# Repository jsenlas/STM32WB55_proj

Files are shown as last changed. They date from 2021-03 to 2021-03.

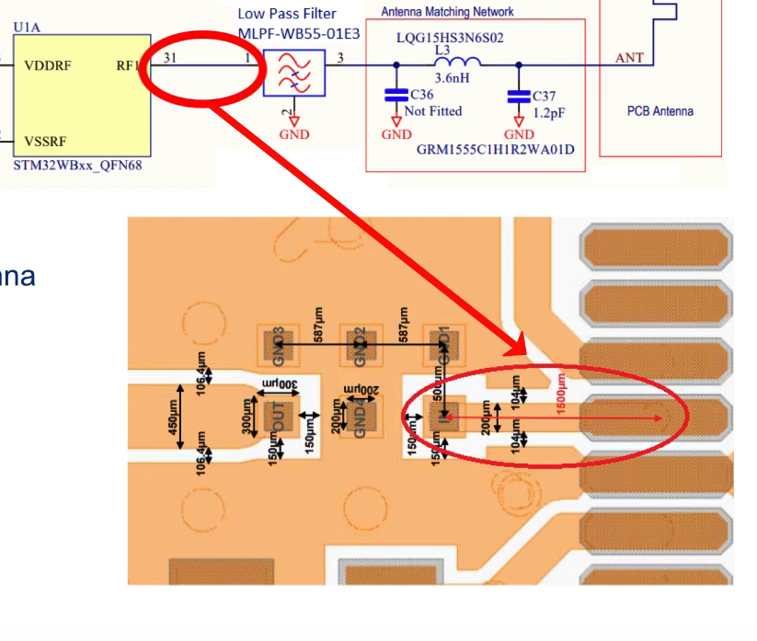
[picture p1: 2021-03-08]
pic/RF.png

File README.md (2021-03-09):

# STM32WB55_proj

# Changelist
v01 
pred touto verziou boli len inicializacne commity
Zacal som minimalizaciu (susciastky blizsie a hustejsie), napriek tomu, ze este nemam spatnu vazbu, no je lepsie ked si prejdem umiestnenie a rozlozenie vsetkych suciastok.
Differential pair pre USB W0.341mm Separator0.2mm to by malo zarucit 90Ohm impedanciu.
Upratovanie Silkscreenu
Pridane 3d Modely .step subory

v02 8.3.2021
- otrasovane
- vyplnene plochy GND
- opravene vsetky chyby, ktore vznikali pri design rules checku
- pridanych par obrazkov, v ktorych je ulozene nastavenie pre niektore operacie, hlavne zony

v03 9.3.2021
- opravene RF trasy - zaoblenie, solder mask, vzdialenost vzhladom na dlzku anteny
- posunute USB dalej, aby som vytvoril priestor a napravil tak dalsie chyby kde sa mi prekryvali suciastky

ToDo:
- [] vyplnit priestor s vias na GND
- [] nepaci sa mi ako je poprepajane I2C (chaos) a USB (+ a - su prilis blizko pri sebe v USBLC6-2SC6)
- [x] doplnit "ohradu" z  GND vias okolo RF tras - nie je miesto

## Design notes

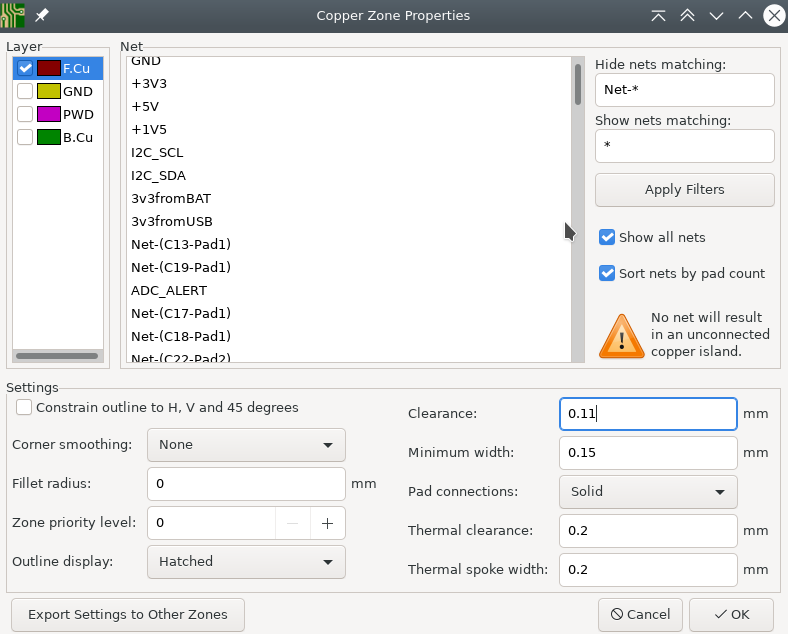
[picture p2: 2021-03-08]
pic/impedance_i2C.png

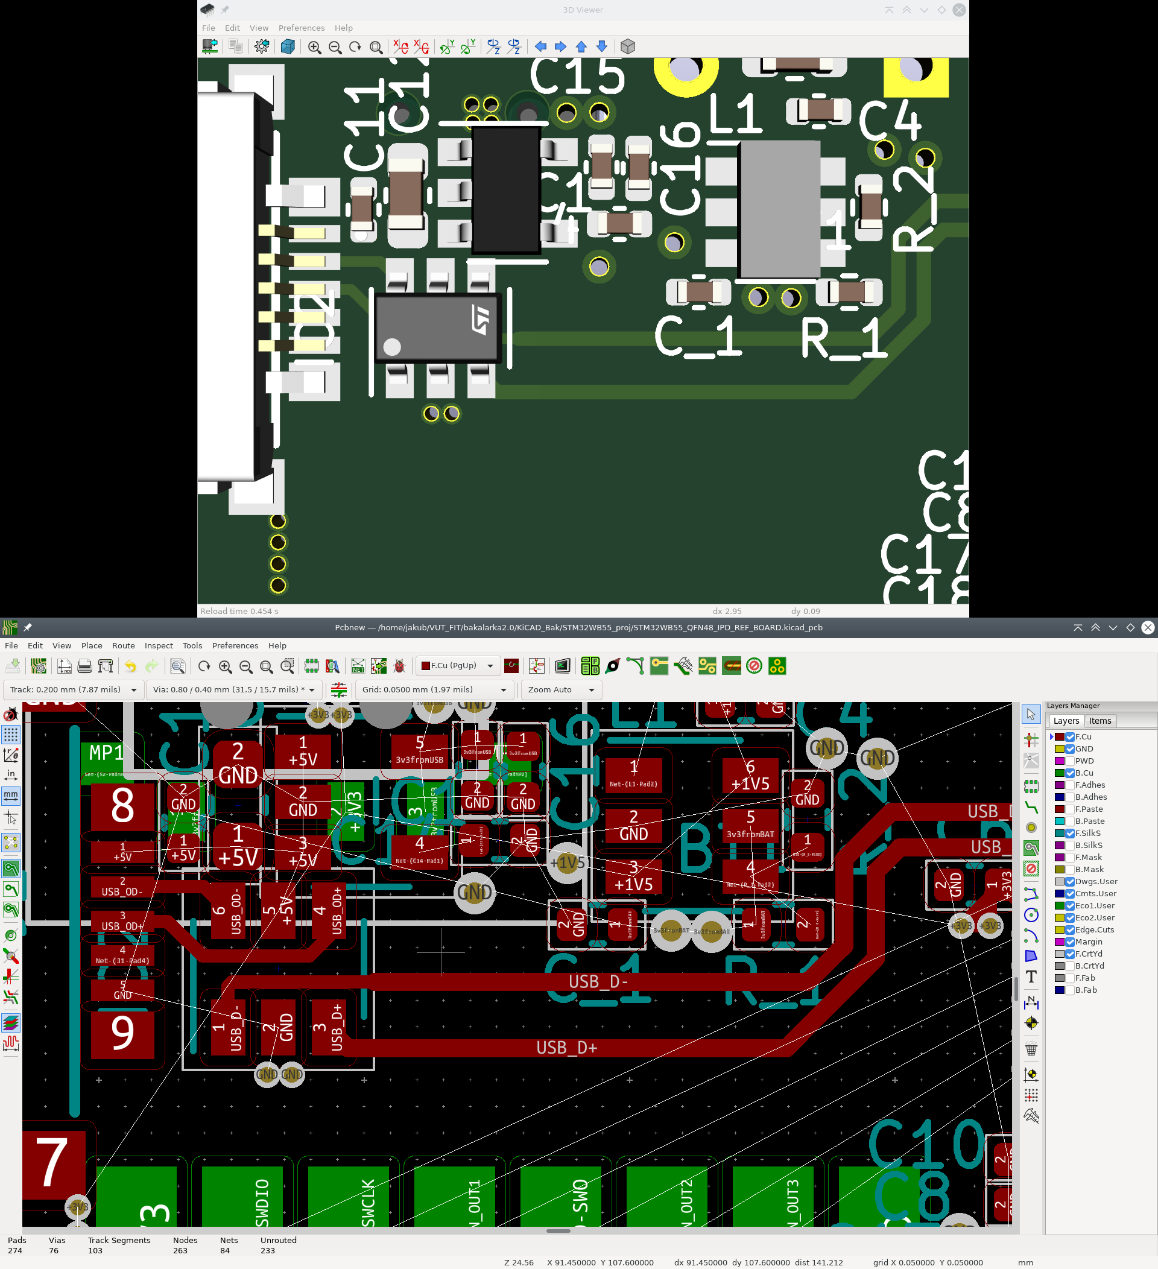
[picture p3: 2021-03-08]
pic/USB_straight.png

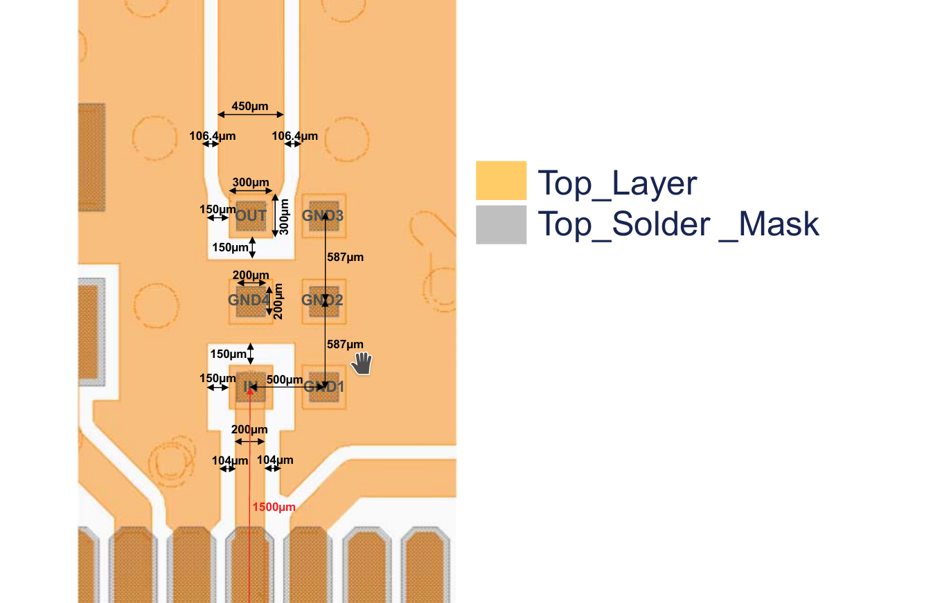
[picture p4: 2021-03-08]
pic/RF_org.png

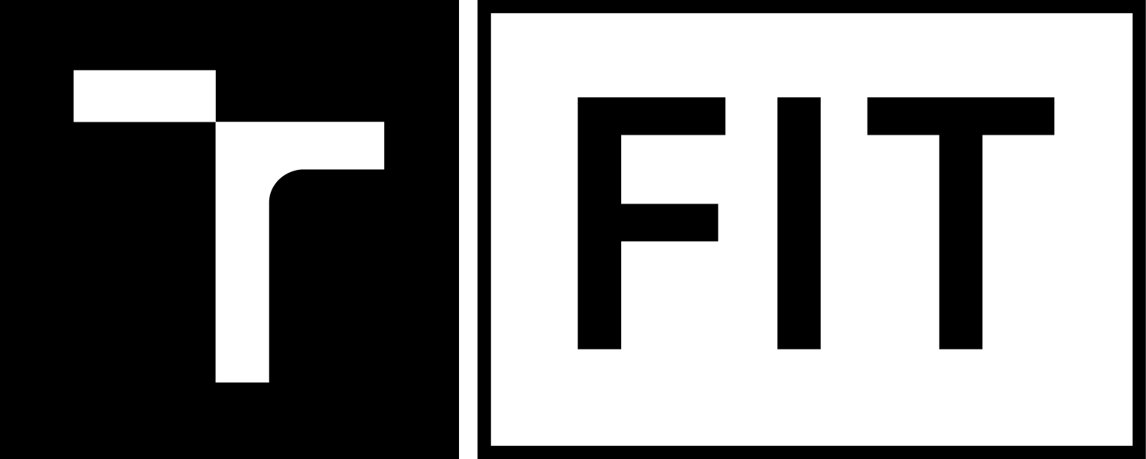
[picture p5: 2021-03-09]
pic/FIT_zkratka_cernobile_CZ.png

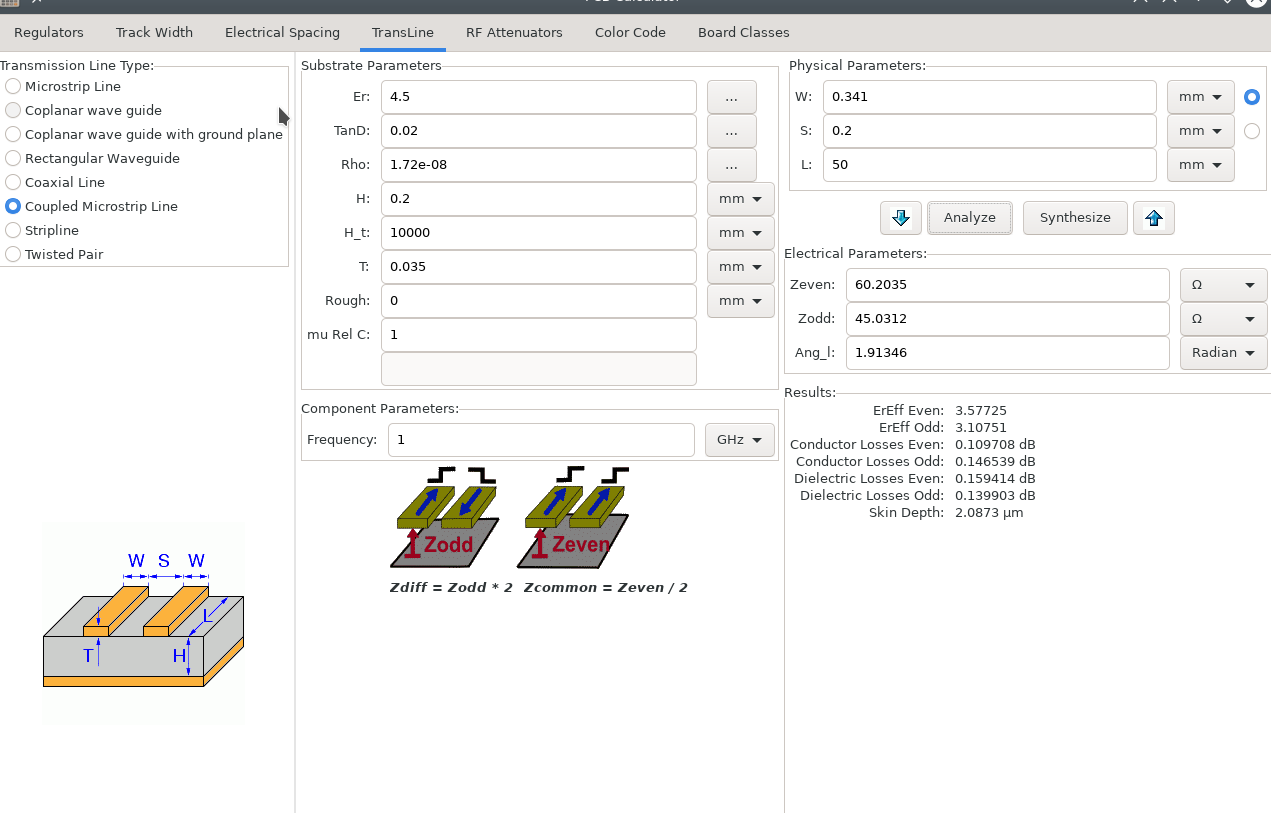
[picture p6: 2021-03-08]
pic/impedance_90_USB.png

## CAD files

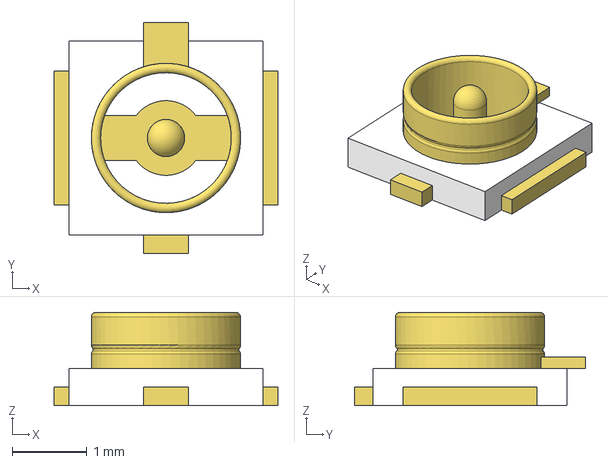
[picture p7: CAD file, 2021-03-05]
mylibs.3d/Taoglas_-_RECE.20279.001E.01.step
3.00 x 3.10 x 1.25 mm

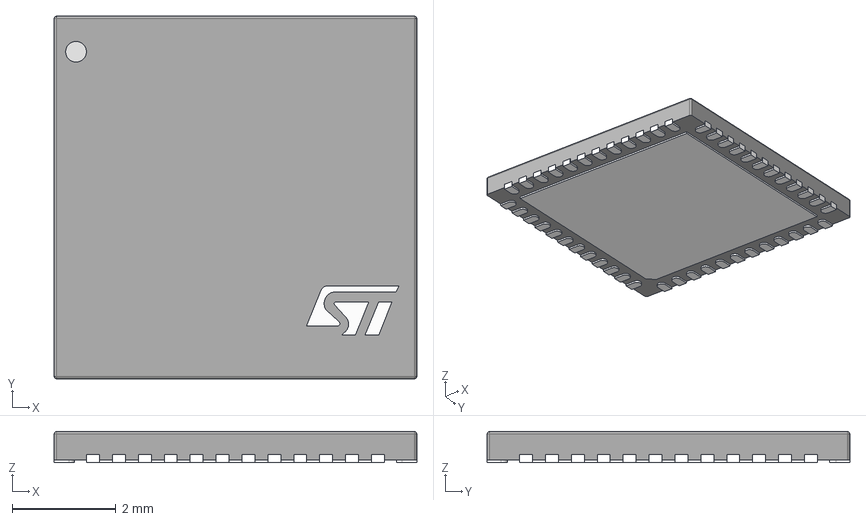
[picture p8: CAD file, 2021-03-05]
mylibs.3d/STMicroelectronics_-_STM32WB55CEU6.step
7.00 x 7.01 x 0.601 mm
circle
STMicroelectronics

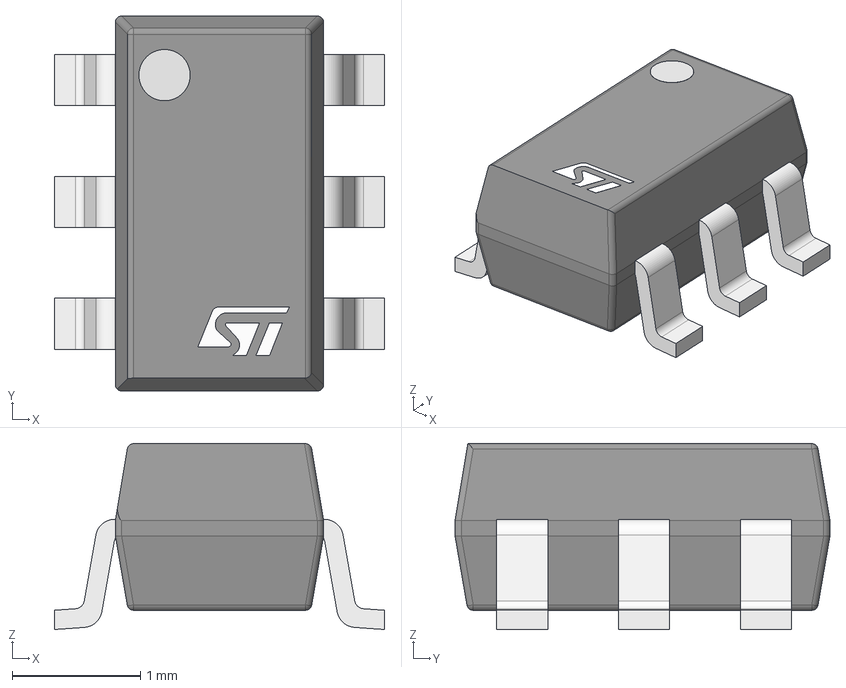
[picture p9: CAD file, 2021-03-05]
mylibs.3d/STMicroelectronics_-_USBLC6-2SC6.step
2.58 x 2.92 x 1.45 mm
IC_BODY
IC_LEG x 3
circle
STMicroelectronics
IC_LEG_MIR1 x 3

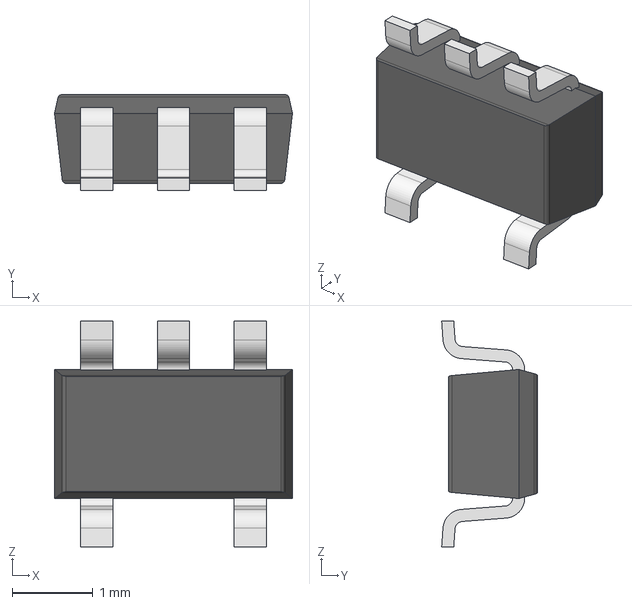
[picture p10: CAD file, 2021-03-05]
mylibs.3d/ld3985m33r.stp
2.95 x 1.19 x 2.80 mm

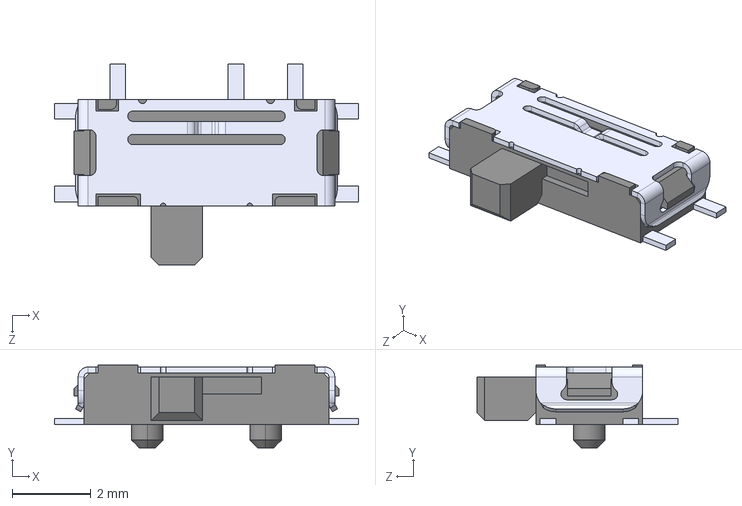
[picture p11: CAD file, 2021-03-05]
mylibs.3d/MLL1200S--3DModel-STEP-56544.STEP
7.70 x 2.10 x 5.10 mm

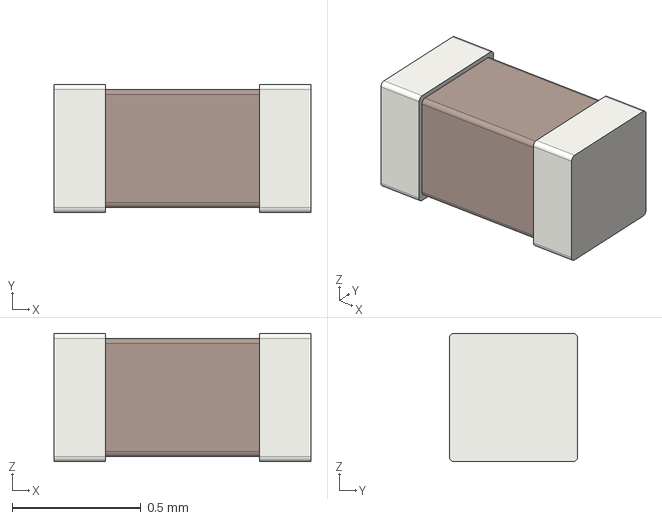
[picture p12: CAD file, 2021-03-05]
mylibs.3d/C_0402_1005Metric.step
1.00 x 0.5 x 0.5 mm

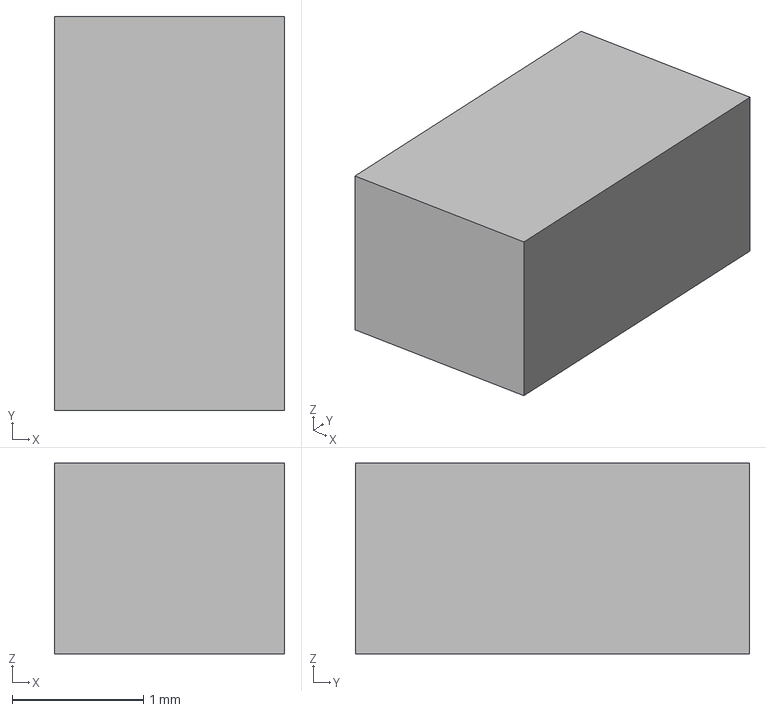
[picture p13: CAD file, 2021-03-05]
mylibs.3d/STMicroelectronics_-_LD3985M33R.step
1.75 x 3.00 x 1.45 mm

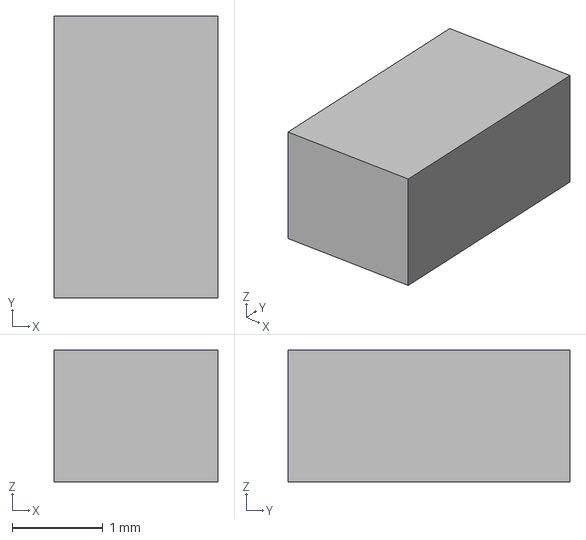
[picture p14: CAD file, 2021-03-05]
mylibs.3d/MCP1640_CHY.step
1.80 x 3.10 x 1.45 mm

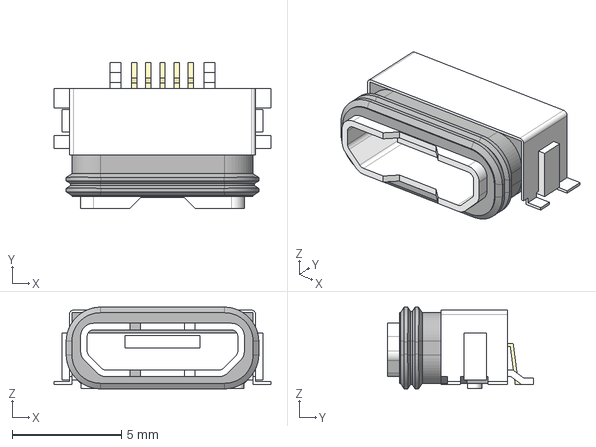
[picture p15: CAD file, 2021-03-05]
mylibs.3d/JST_-_UB-MC5BR3-SDWP604-4S-TF.step
9.94 x 6.70 x 3.75 mm

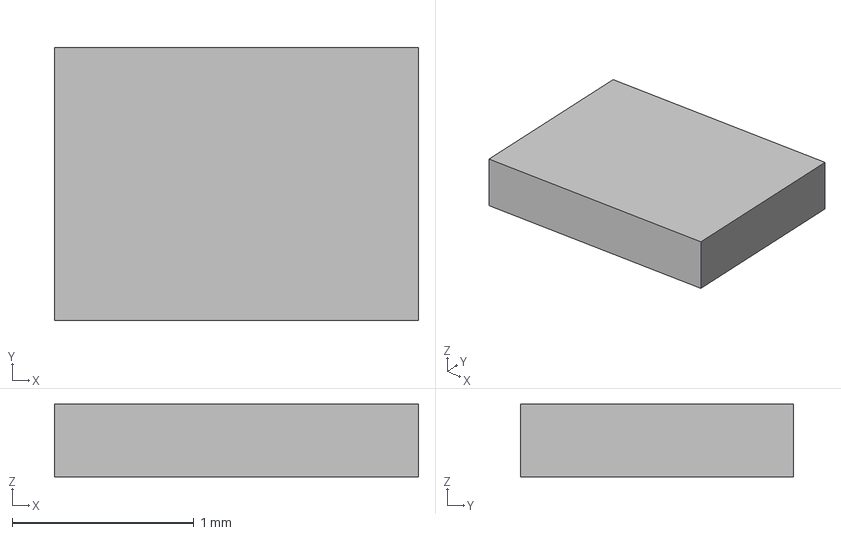
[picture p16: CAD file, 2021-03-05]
mylibs.3d/Texas_Instruments_-_ADS1115IRUGT.step
2.00 x 1.50 x 0.4 mm

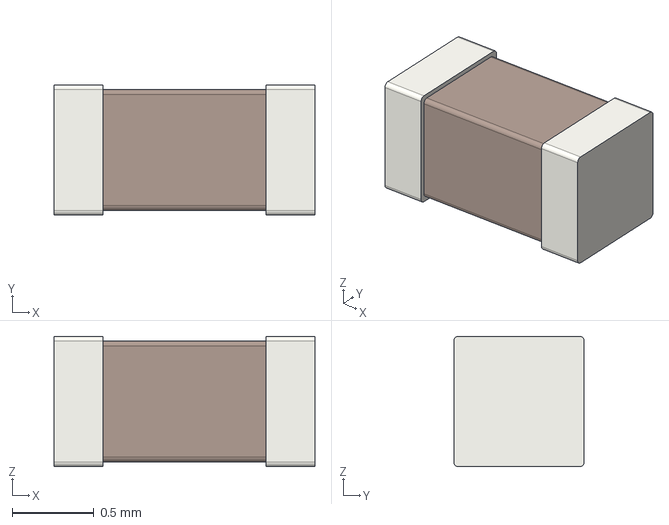
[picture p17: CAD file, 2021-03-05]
mylibs.3d/C_0603_1608Metric.step
1.60 x 0.8 x 0.8 mm

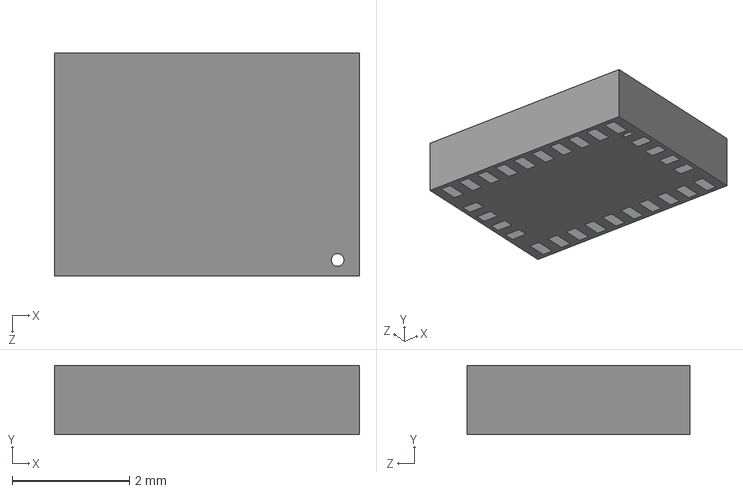
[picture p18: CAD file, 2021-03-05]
mylibs.3d/BNO055--3DModel-STEP-56544.STEP
5.20 x 1.18 x 3.80 mm

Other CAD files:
mylibs.3d/2012.stp
mylibs.3d/2012.obj

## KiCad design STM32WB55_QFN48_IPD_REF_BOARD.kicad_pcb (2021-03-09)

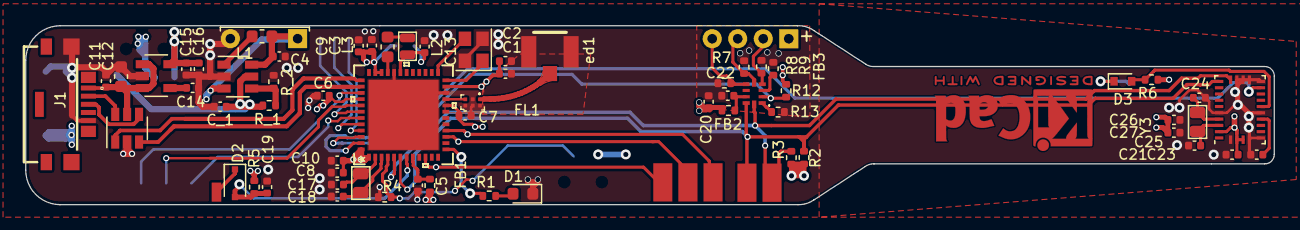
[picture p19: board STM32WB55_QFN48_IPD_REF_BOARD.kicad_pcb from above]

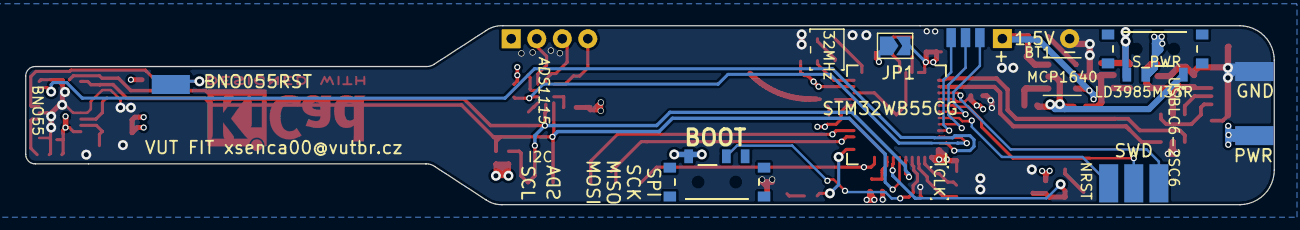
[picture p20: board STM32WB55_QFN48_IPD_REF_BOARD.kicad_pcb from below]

Board: 4 copper layers, 99.4 x 14.3 mm, 76 parts (8 on the bottom side), 52 nets.

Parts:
32MHz: NX2520SA-32MHz; Crystal_SMD_2520-4Pin_2.5x2.0mm
ADS1115: ADS1115IDGS; ADS1115IRUGR
BNO55: BNO055_my; LGA-28_5.2x3.8mm_P0.5mm
BNO055RST: Conn_01x01_Male; pin_01
BOOT: MLL1200S
BT1: Battery_Cell; battery_connector_narrow
C1, C5, C6, C7, C8, C9, C10, C15, C19, C21, C23, C26, C27: 100n; C_0402_1005Metric
C2: 100p; C_0402_1005Metric
C3, C4, C13: 4u7; C_0402_1005Metric
C11, C16, C20, C22: 1u; C_0402_1005Metric
C12: 100n; C_0603_1608Metric
C14: 10n; C_0402_1005Metric
C17, C18: 4p3; C_0402_1005Metric
C24, C25: 22p; C_0402_1005Metric
CLK: NX2012SA-32768K; Crystal_2012_custom
C_1: 10u; C_0402_1005Metric
D1: LED Blue; LED_0603_1608Metric
D2: BAT54J; D_SOD-323F
D3: 1N4148WT; D_SOD-523
FB1: BLM15AX601SN1D; R_0402_1005Metric
FB2, FB3: MMZ2012Y152BTD25; R_0402_1005Metric
FL1: MLPF-WB55-01E3; MLPF-WB55-02E3
GND: Conn_01x01_Male; pin_01
I2C: Conn_01x02_Male; pin_02
J1: USB_B_Micro; UB-MC5BR3-SDWP604-4S-TF
J4: Conn_01x04_Male; Pin_FSR
JP1: SolderJumper Open; SolderJumper-2_P1.3mm_Open_TrianglePad1.0x1.5mm
J_GEN1: Conn_01x03_Male; pin_03
J_SPI1: Conn_01x03_Male; pin_03
L1: 4u7; L_0603_1608Metric
L2: 10u; L_0712_SMD
L3: 10n; L_0603_1608Metric
LD3985M33R: LD3985M33R; SOT-23-5
MCP1640: MCP1640CCH; SOT-23-6
N1: Housing; KiCad-Logo2_5mm_Copper
NRST: Conn_01x01_Male; pin_01
PWR: Conn_01x01_Male; pin_01
R1, R5, R7, R8, R9: 100K; R_0402_1005Metric
R2, R3, R4, R6, R12, R13: 10K; R_0402_1005Metric
R_1: 976k; R_0402_1005Metric
R_2: 562k; R_0402_1005Metric
SWD: Conn_01x03_Male; pin_03
S_PWR: MLL1200S
U2: STM32WB55CG; STM32WB55CGU7
USBLC6-2SC6: USBLC6-2SC6; SOT-23-6
Y3: NX2012SA-32768K; Crystal_2012_custom
ed1: RECE.20279.001E.01

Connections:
3v3fromBAT: C_1.1, MCP1640.5, R_1.1, S_PWR.1
3v3fromUSB: C15.1, C16.1, LD3985M33R.5, S_PWR.3
+1V5: BT1.1, C4.1, L1.1, MCP1640.3, MCP1640.6
+3V3: BNO55.3, BNO55.4, BNO55.28, BOOT.1, C1.1, C2.1, C3.1, C6.1, C7.1, C8.1, C9.1, C10.1, C20.2, C21.1, C26.1, C27.1, FB1.1, FB2.1, J4.1, JP1.2, PWR.1, R2.1, R3.1, R5.1, R6.1, R12.1, S_PWR.2, U2.1, U2.20, U2.23, U2.34, U2.35, U2.40, U2.48
+5V: C11.1, C12.1, J1.1, LD3985M33R.1, LD3985M33R.3, USBLC6-2SC6.5
/R_OUT: FL1.1, ed1.3
ADC_ALERT: ADS1115.2, R12.2, U2.46
BNO055_INT: BNO55.14, U2.47
BNO055_RESET: BNO055RST.1, D3.1
GENERAL_PIN_OUT1: J_GEN1.1, U2.42
GENERAL_PIN_OUT2: J_GEN1.2, U2.44
GENERAL_PIN_OUT3: J_GEN1.3, U2.45
GND: 32MHz.2, 32MHz.4, BNO55.2, BNO55.5, BNO55.6, BNO55.10, BNO55.15, BNO55.16, BNO55.17, BNO55.18, BNO55.25, BT1.2, C1.2, C2.2, C3.2, C4.2, C5.2, C6.2, C7.2, C8.2, C9.2, C10.2, C11.2, C12.2, C13.2, C14.2, C15.2, C16.2, C17.2, C18.2, C19.2, C20.1, C21.2, C22.1, C23.2, C24.2, C25.2, C26.2, C27.2, C_1.2, D1.1, FB3.2, FL1.2, FL1.4, FL1.5, FL1.6, GND.1, J1.5, J1.6, LD3985M33R.2, MCP1640.2, R4.2, R7.2, R8.2, R9.2, R13.2, R_2.2, U2.22, U2.32, U2.49, USBLC6-2SC6.2, ed1.1, ed1.2
I2C_SCL: ADS1115.10, BNO55.19, I2C.1, R3.2, U2.5
I2C_SDA: ADS1115.9, BNO55.20, I2C.2, R2.2, U2.6
LED_BLUE: R1.1, U2.13
NRST: D2.1, NRST.1
unnamed: ADS1115.1, R13.1
unnamed: ADS1115.3, FB3.1
unnamed: ADS1115.4, J4.2, R9.1
unnamed: ADS1115.5, J4.3, R8.1
unnamed: ADS1115.6, J4.4, R7.1
unnamed: ADS1115.8, C22.2, FB2.2
unnamed: BNO55.9, C23.1
unnamed: BNO55.11, D3.2, R6.2
unnamed: BNO55.26, C24.1, Y3.1
unnamed: BNO55.27, C25.1, Y3.2
unnamed: C5.1, FB1.2, U2.8
unnamed: C13.1, JP1.1, L2.1, U2.31
unnamed: C14.1, LD3985M33R.4
unnamed: C17.1, CLK.2, U2.2
unnamed: C18.1, CLK.1, U2.3
unnamed: C19.1, D2.2, R5.2, U2.7
unnamed: D1.2, R1.2
unnamed: L1.2, MCP1640.1
unnamed: L2.2, L3.1
unnamed: L3.2, U2.33
unnamed: MCP1640.4, R_1.2, R_2.1
unnamed: BOOT.2, R4.1, U2.4
unnamed: 32MHz.1, U2.24
unnamed: 32MHz.3, U2.25
RF1: FL1.3, U2.21
SPI_MISO: J_SPI1.2, U2.15
SPI_MOSI: J_SPI1.1, U2.16
SPI_SCK: J_SPI1.3, U2.10
SYS_JTCK-SWCLK: SWD.2, U2.41
SYS_JTDO-SWO: SWD.3, U2.43
SYS_JTMS-SWDIO: SWD.1, U2.39
USB_D+: U2.38, USBLC6-2SC6.3
USB_D-: U2.37, USBLC6-2SC6.1
USB_OD+: J1.3, USBLC6-2SC6.4
USB_OD-: J1.2, USBLC6-2SC6.6

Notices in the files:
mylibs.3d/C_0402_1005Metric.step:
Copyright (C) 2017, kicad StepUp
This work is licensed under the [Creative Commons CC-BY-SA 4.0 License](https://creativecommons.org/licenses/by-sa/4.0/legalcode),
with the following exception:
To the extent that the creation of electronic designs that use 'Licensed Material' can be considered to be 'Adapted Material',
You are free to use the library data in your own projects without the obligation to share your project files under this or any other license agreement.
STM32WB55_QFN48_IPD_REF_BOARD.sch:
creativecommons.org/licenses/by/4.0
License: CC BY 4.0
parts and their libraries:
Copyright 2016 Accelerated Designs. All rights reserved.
